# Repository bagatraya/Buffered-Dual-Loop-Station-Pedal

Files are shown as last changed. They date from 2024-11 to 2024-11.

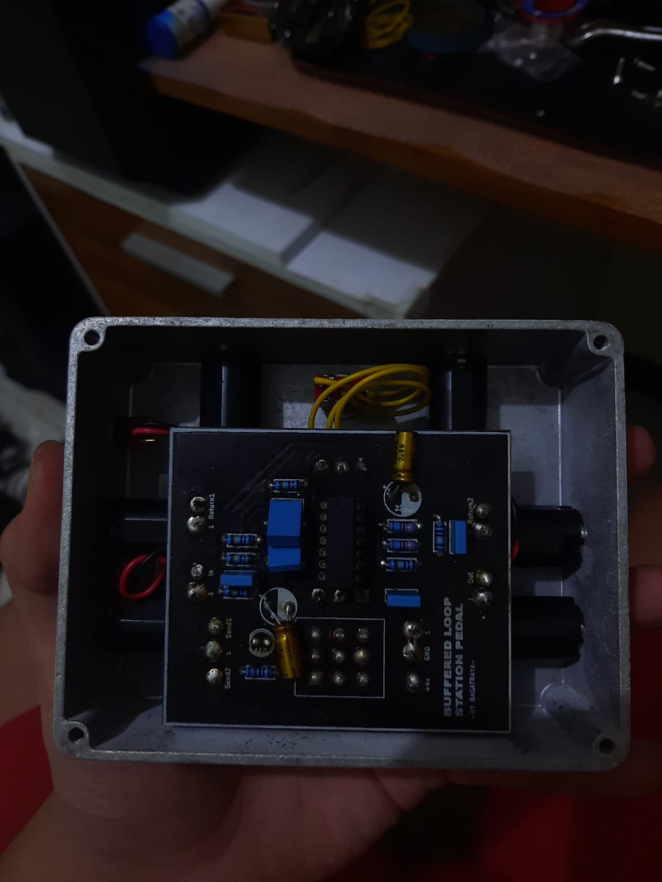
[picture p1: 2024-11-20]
Buffered-Dual-Loop-Station-Pedal/Documentation/5.jpg

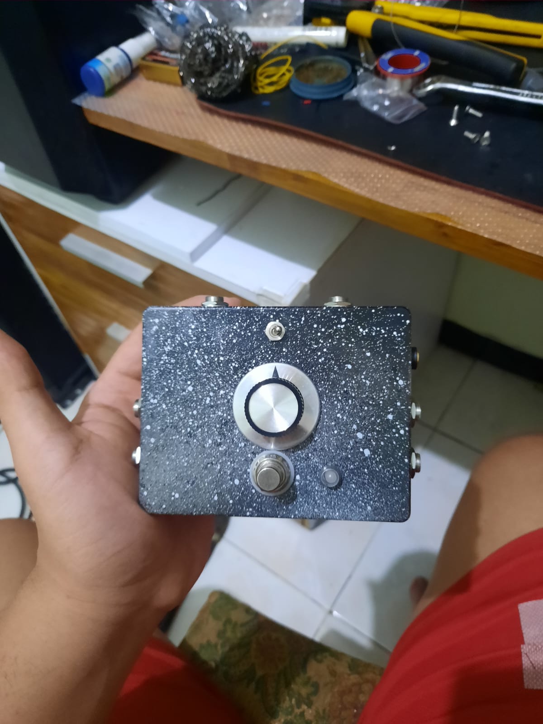
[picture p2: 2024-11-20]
Buffered-Dual-Loop-Station-Pedal/Documentation/6.jpg

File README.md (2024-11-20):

# Buffered-Dual-Loop-Station-Pedal
A project showcasing the design and development of a Buffered Dual Loop Station Effect Pedal, using the TL074 op-amp for low-noise buffering and inverting circuits. This repository includes the schematic, PCB design, simulation files, and a detailed project report.

## Features  
- **Buffered Input and Outputs**: Maintains signal integrity with low-noise TL074 op-amps.  
- **Phase Inversion**: Switchable inverting circuit for phase adjustment on Return 1.  
- **Signal Blending**: Blend potentiometer to control the balance between two return signals.  
- **Live-Tested**: Successfully used in live performance settings.  

## Repository Contents  
- **Hardware**: Schematic, PCB designs, and Bill of Materials (BOM).  
- **Simulations**: Proteus simulation files and results.  
- **Photos and Demos**: Images and video of the build and live testing.

## Simulation
WhatsApp Image 2024-11-06 at 13 19 08_4e2e42fc
WhatsApp Image 2024-11-06 at 13 19 08_1d4611a7

## PCB Circuit
WhatsApp Image 2024-11-20 at 22 16 17_e44410e7

## PCB Design
WhatsApp Image 2024-11-06 at 14 10 15_3a9c0417

## Final Result
WhatsApp Image 2024-11-20 at 22 17 19_efe885c9
WhatsApp Image 2024-11-20 at 22 17 20_f0106ce3

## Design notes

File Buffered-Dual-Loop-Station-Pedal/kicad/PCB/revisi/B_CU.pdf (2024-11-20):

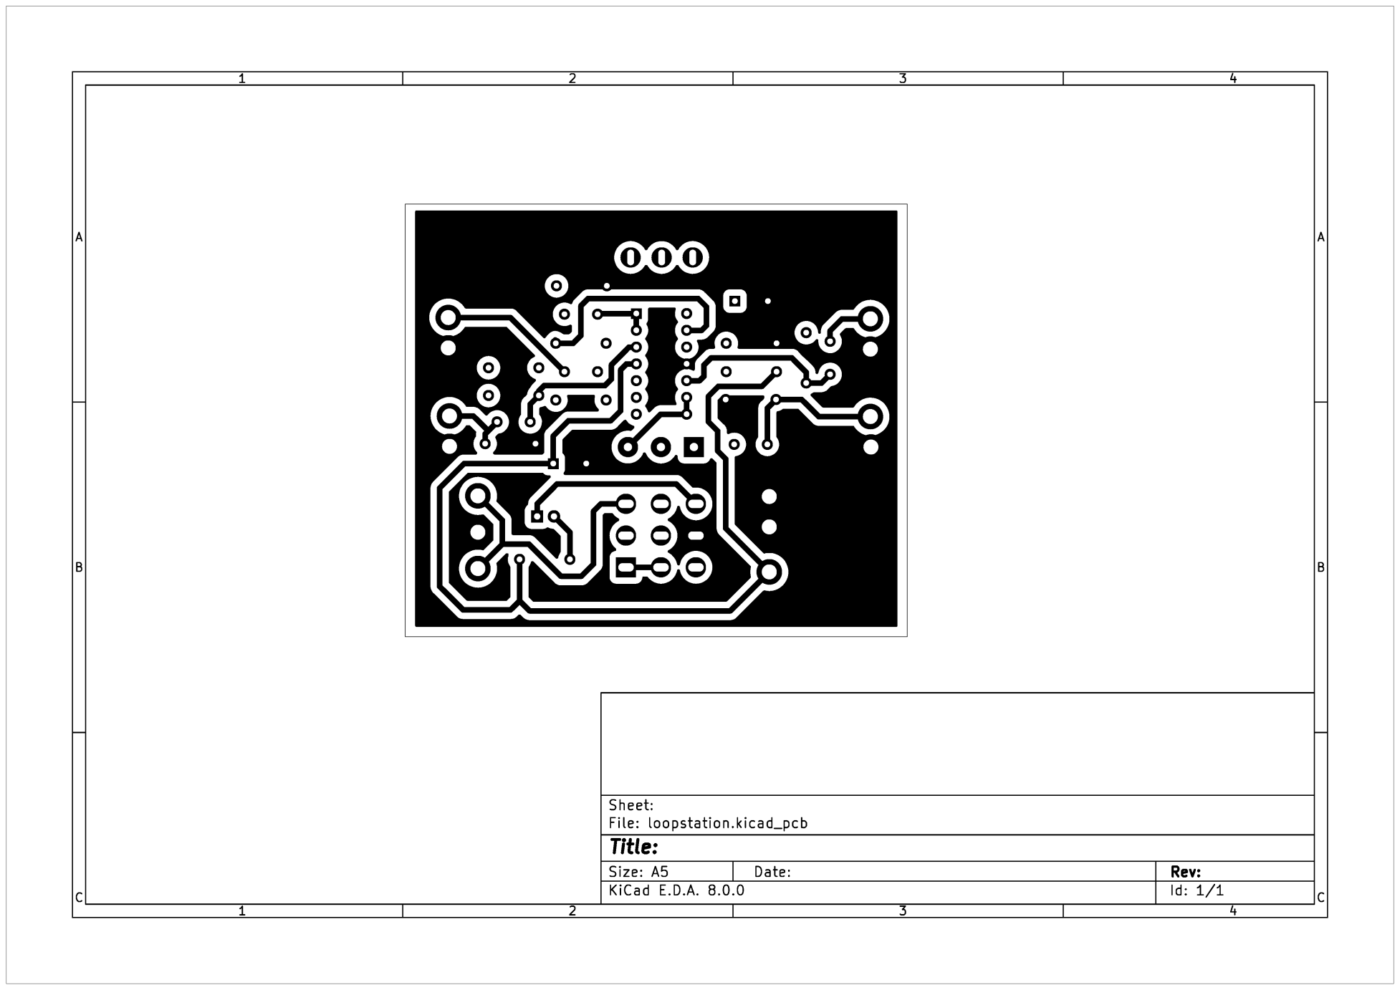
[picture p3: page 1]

2 | 3
A | A

B

Sheet:
File: loopstation.kicad_pcb
Title:
Size: A5 | Date: | Rev:
c~---------,.--------r-----------.,-~Ki_C_ad_E_.D_.A_._B_._o.ro _______ .-----------r----~-ld_:_1_/_1-,,----~c

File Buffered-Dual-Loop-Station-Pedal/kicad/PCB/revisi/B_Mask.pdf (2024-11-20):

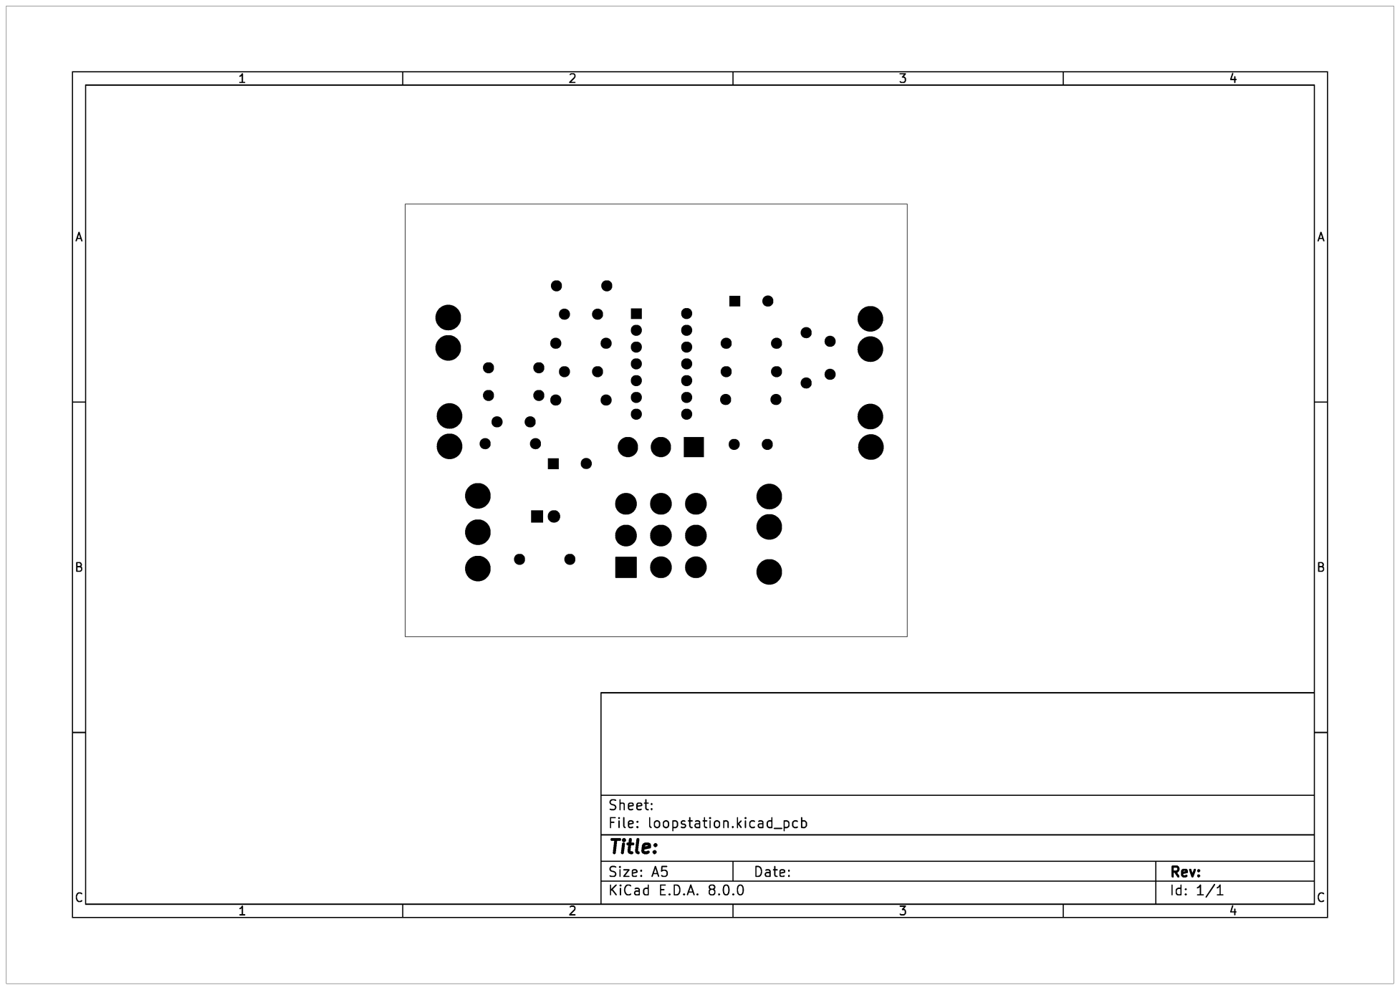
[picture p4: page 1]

1 | 2 | I | 3 | I | 4
A | A
- •
- | ■ | • | • • • ■ | • • • | • • • • • • • • •
- • • • • • • • • • • • •
- •• • • • • • • • • | • • | • • • • | ••• • • ■ | • | • • •• ••• • B | • • •• • • • • • •• • | B

Sheet:
File: loopstation.kicad_pcb
Title:
Size: A5 | I Date: | I Rev:
C | KiCad E.D.A. 8.0.0 | I Id: 1/1 | C 1 | L | ~ | q

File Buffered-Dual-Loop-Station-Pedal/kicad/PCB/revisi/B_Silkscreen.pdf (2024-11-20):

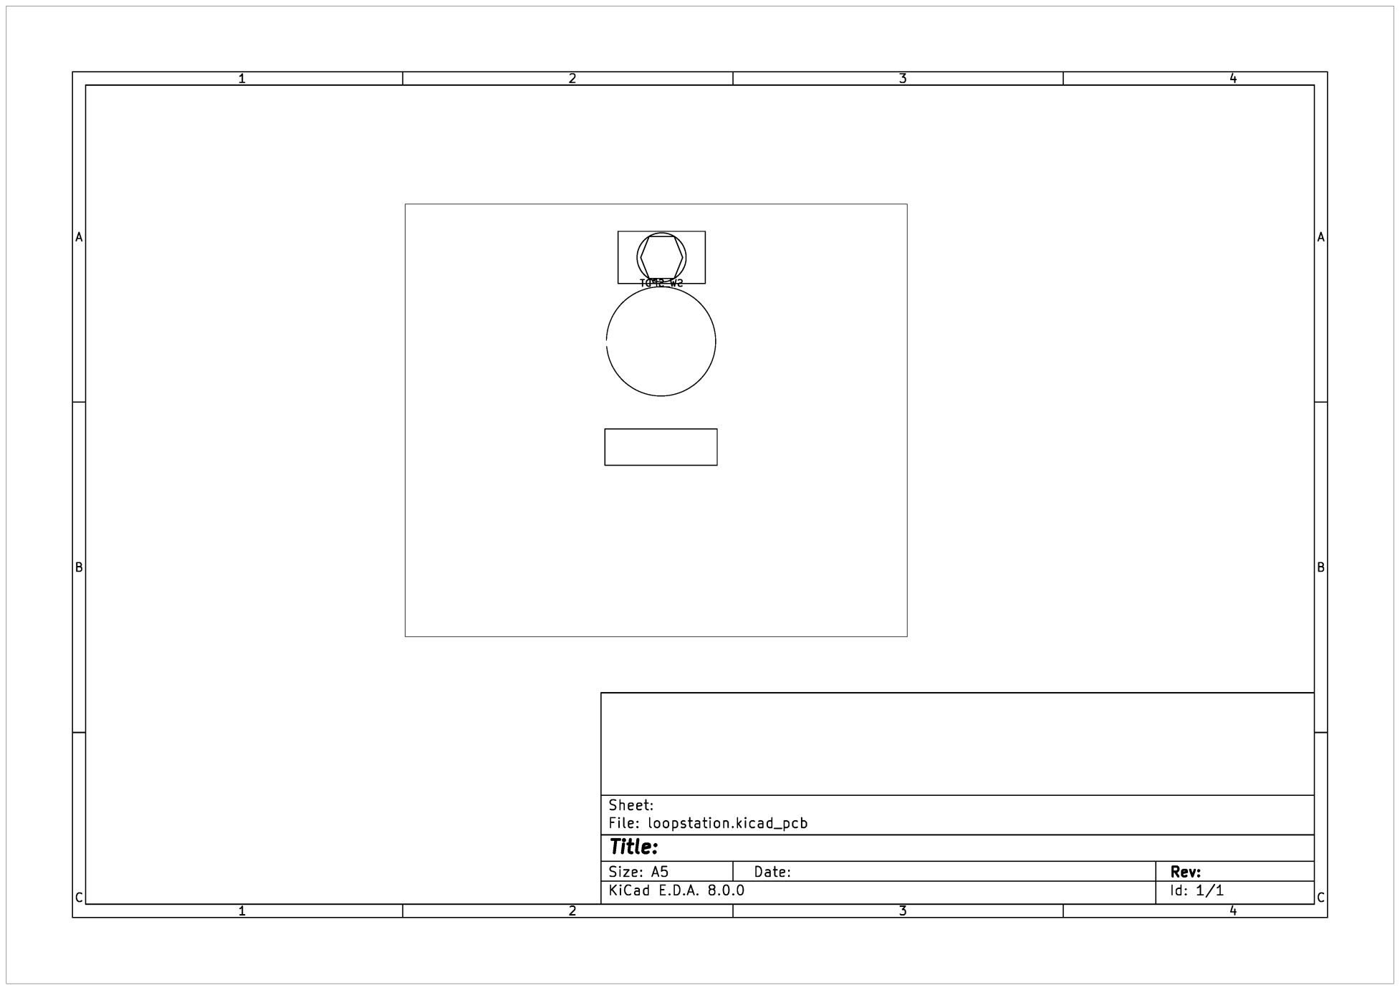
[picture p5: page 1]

1 | 2 | I | 3 | I | 4
A | IOI | A
0
I | I
B | B

Sheet:
File: loopstation.kicad_pcb

## Title:

Size: A5 | I Date: | I Rev:
C | KiCad E.D.A. 8.0.0 | I Id: 1/1 | C 1 | L | ~ | q

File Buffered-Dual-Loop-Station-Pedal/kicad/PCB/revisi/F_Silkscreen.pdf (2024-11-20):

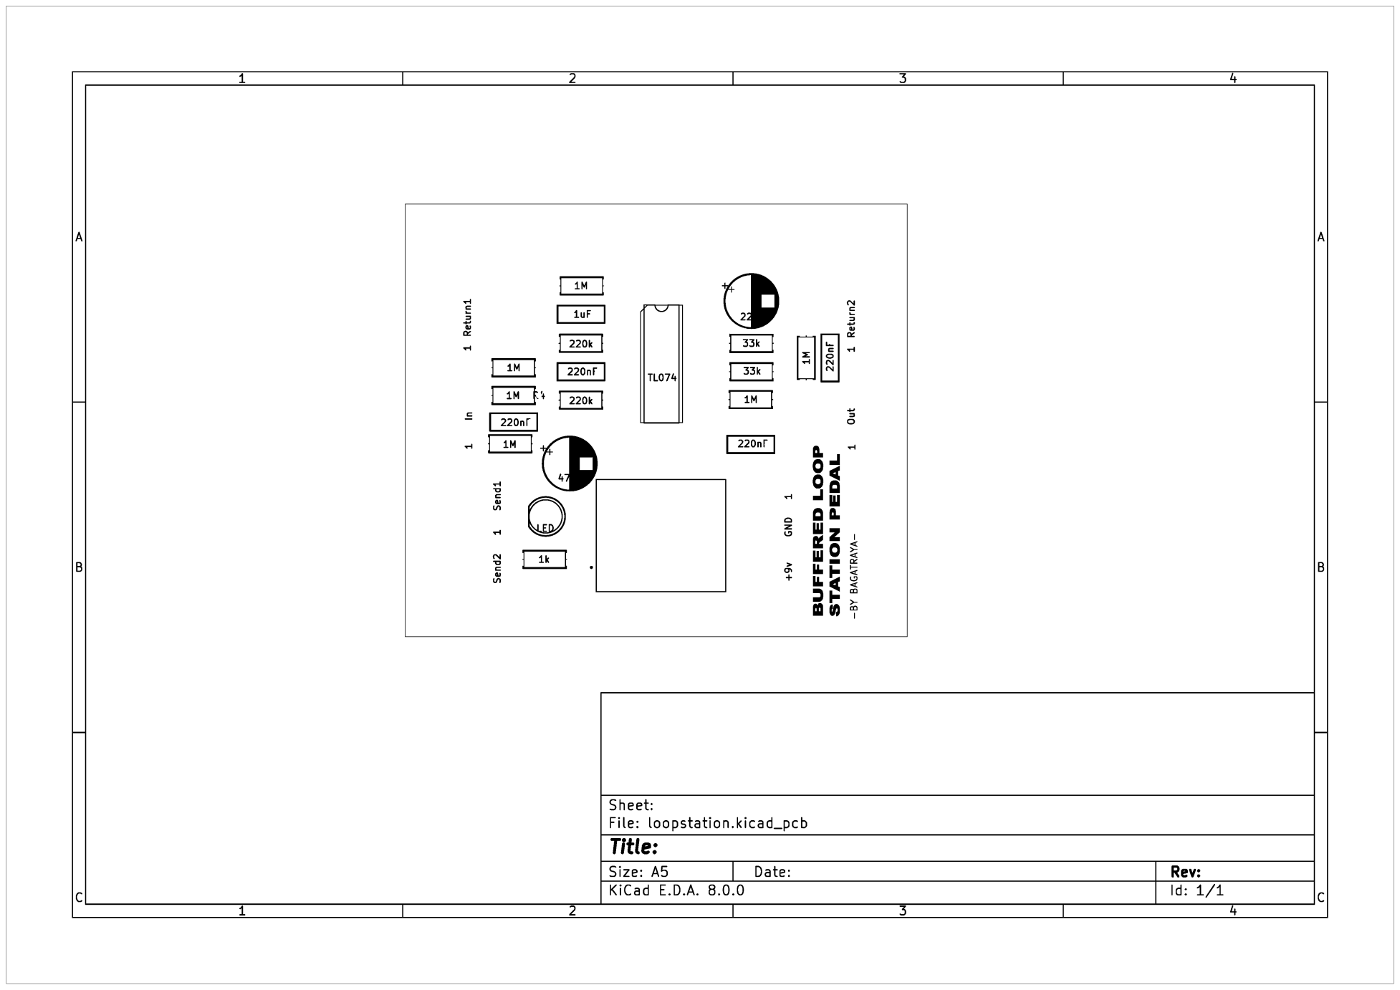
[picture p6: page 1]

2 | I | 3 | I | 4
A | A

~

B

Sheet:
File: loopstation.kicad_pcb
Title:
Size: A5 | I Date: | I Rev:
c~------.--------r-----------.,-~Ki_C_ad_E_.D_.A_._B_._o.ro _______ .-----------r----~l_ld_:_1_/_1-,,----~c 1 | L | j | 4

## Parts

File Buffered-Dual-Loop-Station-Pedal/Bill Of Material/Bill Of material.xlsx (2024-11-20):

NO | nama barang | Harga | jumlah | sub total
1 | PCB | Rp 52000.00 | 1 | Rp 52000.00
2 | Rumah LED 5mm | Rp 2000.00 | 1 | Rp 2000.00
3 | LED 5mm | Rp 700.00 | 2 | Rp 1400.00
4 | resistor 33k | Rp 650.00 | 2 | Rp 1300.00
5 | resistor 220k | Rp 650.00 | 2 | Rp 1300.00
6 | resistor 1k | Rp 650.00 | 1 | Rp 650.00
7 | resistor 1M | Rp 800.00 | 6 | Rp 4800.00
8 | SPDT 3pin ON-ON | Rp 9000.00 | 1 | Rp 9000.00
9 | Socket IC 14 pin | Rp 2500.00 | 1 | Rp 2500.00
10 | Footswitch 3PDT | Rp 26000.00 | 1 | Rp 26000.00
11 | Socket DC 2.1x5.5mm | Rp 3600.00 | 1 | Rp 3600.00
12 | knob potensio | Rp 12500.00 | 1 | Rp 12500.00
13 | potentiometer b25k | Rp 7500.00 | 1 | Rp 7500.00
14 | case alu 1590BB2 | Rp 102000.00 | 1 | Rp 102000.00
15 | cap elco 22uF | Rp 4750.00 | 1 | Rp 4750.00
16 | Epcos 220nF | Rp 2800.00 | 4 | Rp 11200.00
17 | cap elco 47uF | Rp 3500.00 | 1 | Rp 3500.00
18 | Epcos 1uF | Rp 4500.00 | 1 | Rp 4500.00
19 | Socket jack 6.35mm | Rp 6500.00 | 6 | Rp 39000.00
20 | IC TL074 | Rp 6500.00 | 1 | Rp 6500.00
 |  |  | TOTAL | Rp 296000.00

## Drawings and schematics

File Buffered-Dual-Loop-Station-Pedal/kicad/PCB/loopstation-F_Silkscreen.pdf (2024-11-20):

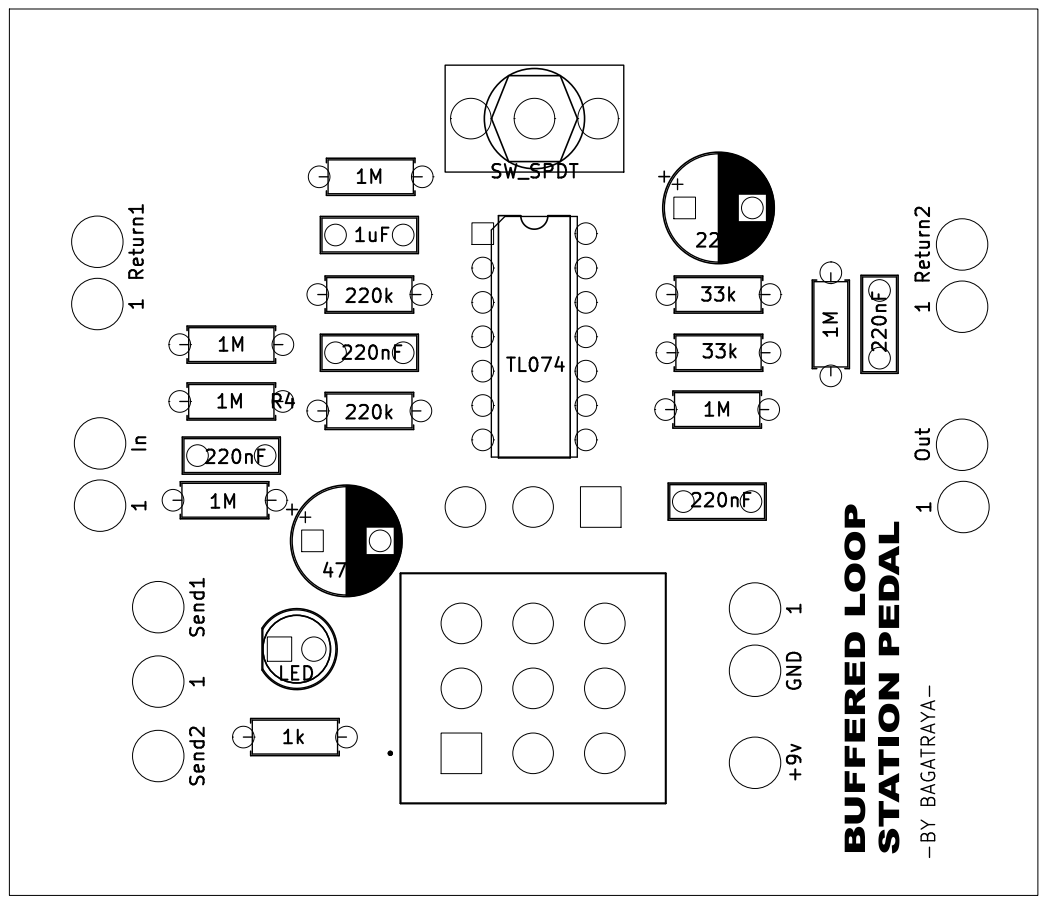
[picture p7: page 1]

BUFFERED LOOP STATION PEDAL -BY BAGATRAYA- Send2 Send1 GND

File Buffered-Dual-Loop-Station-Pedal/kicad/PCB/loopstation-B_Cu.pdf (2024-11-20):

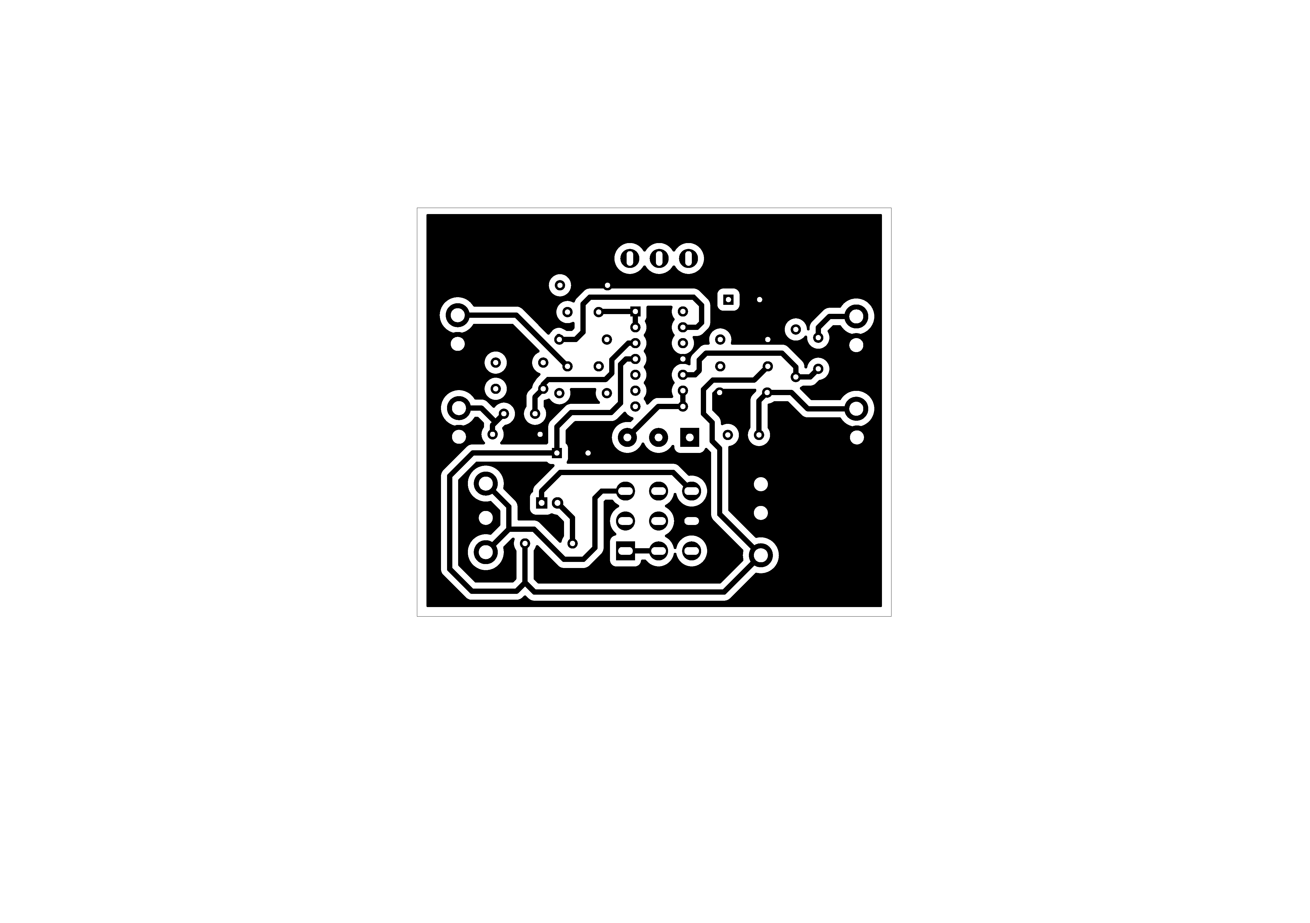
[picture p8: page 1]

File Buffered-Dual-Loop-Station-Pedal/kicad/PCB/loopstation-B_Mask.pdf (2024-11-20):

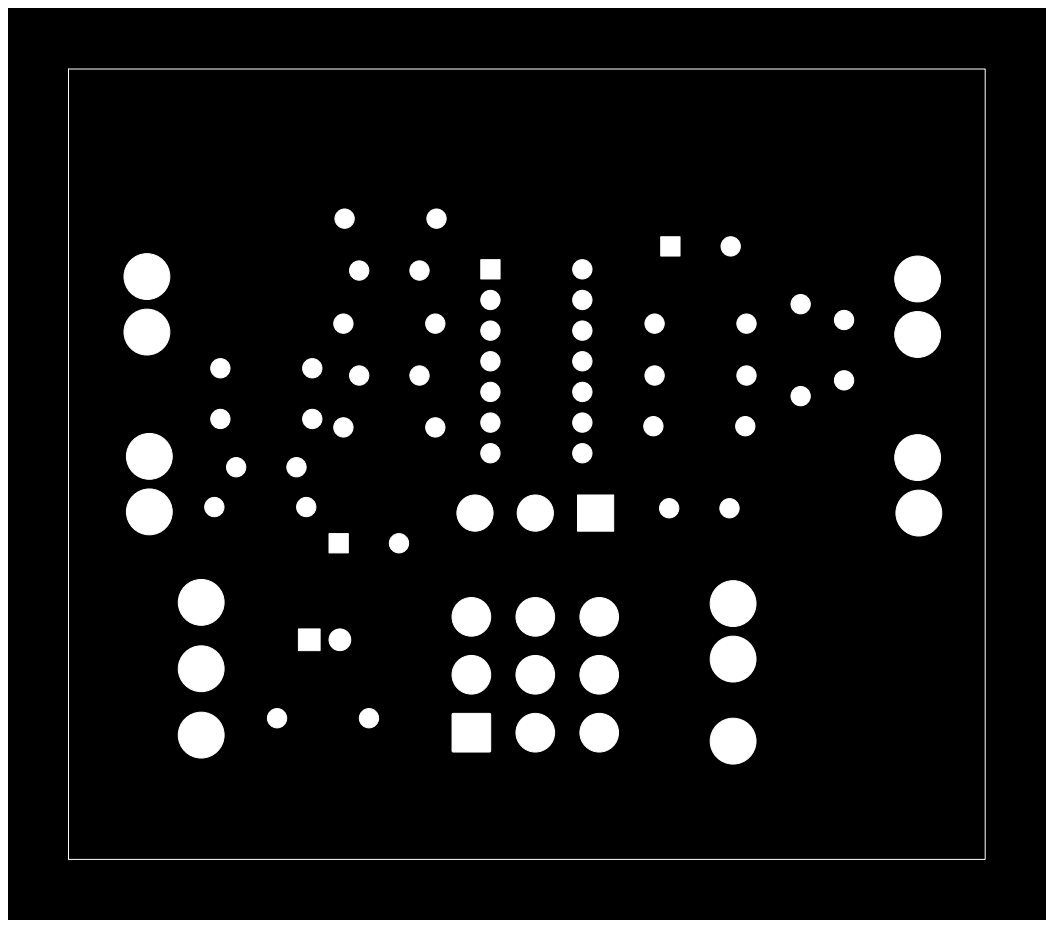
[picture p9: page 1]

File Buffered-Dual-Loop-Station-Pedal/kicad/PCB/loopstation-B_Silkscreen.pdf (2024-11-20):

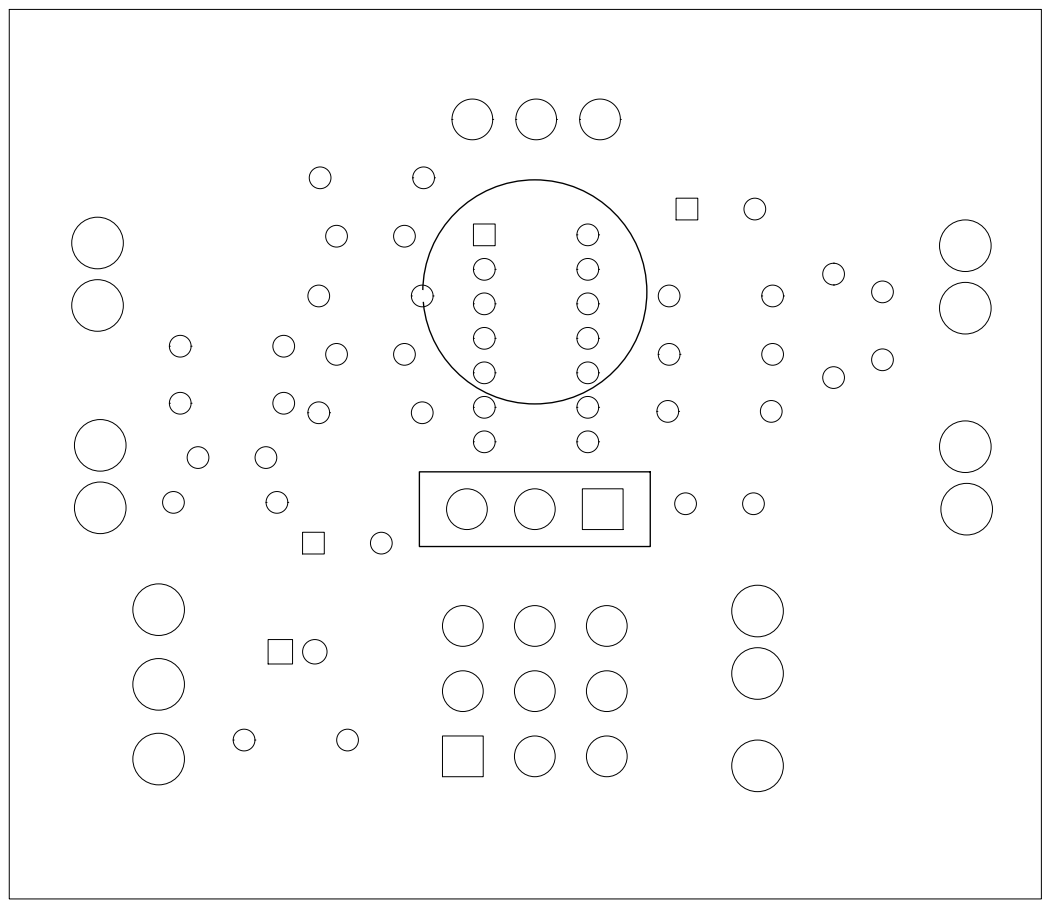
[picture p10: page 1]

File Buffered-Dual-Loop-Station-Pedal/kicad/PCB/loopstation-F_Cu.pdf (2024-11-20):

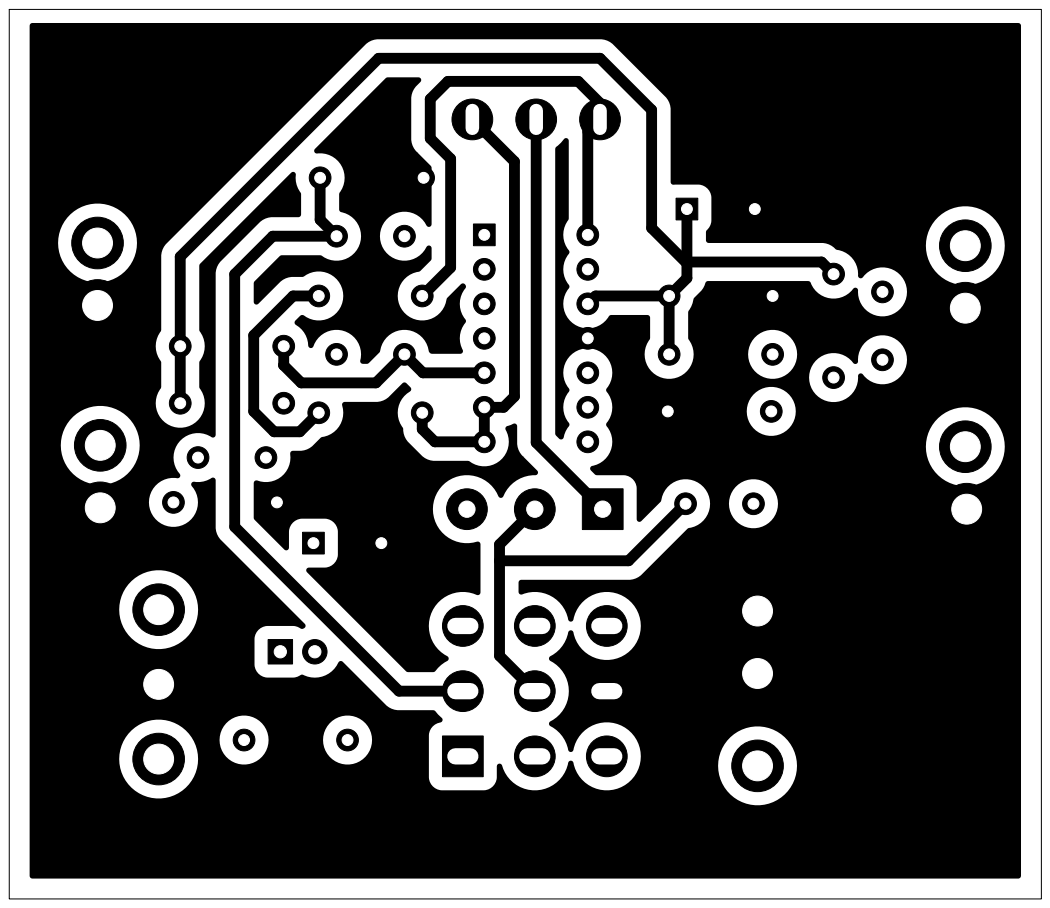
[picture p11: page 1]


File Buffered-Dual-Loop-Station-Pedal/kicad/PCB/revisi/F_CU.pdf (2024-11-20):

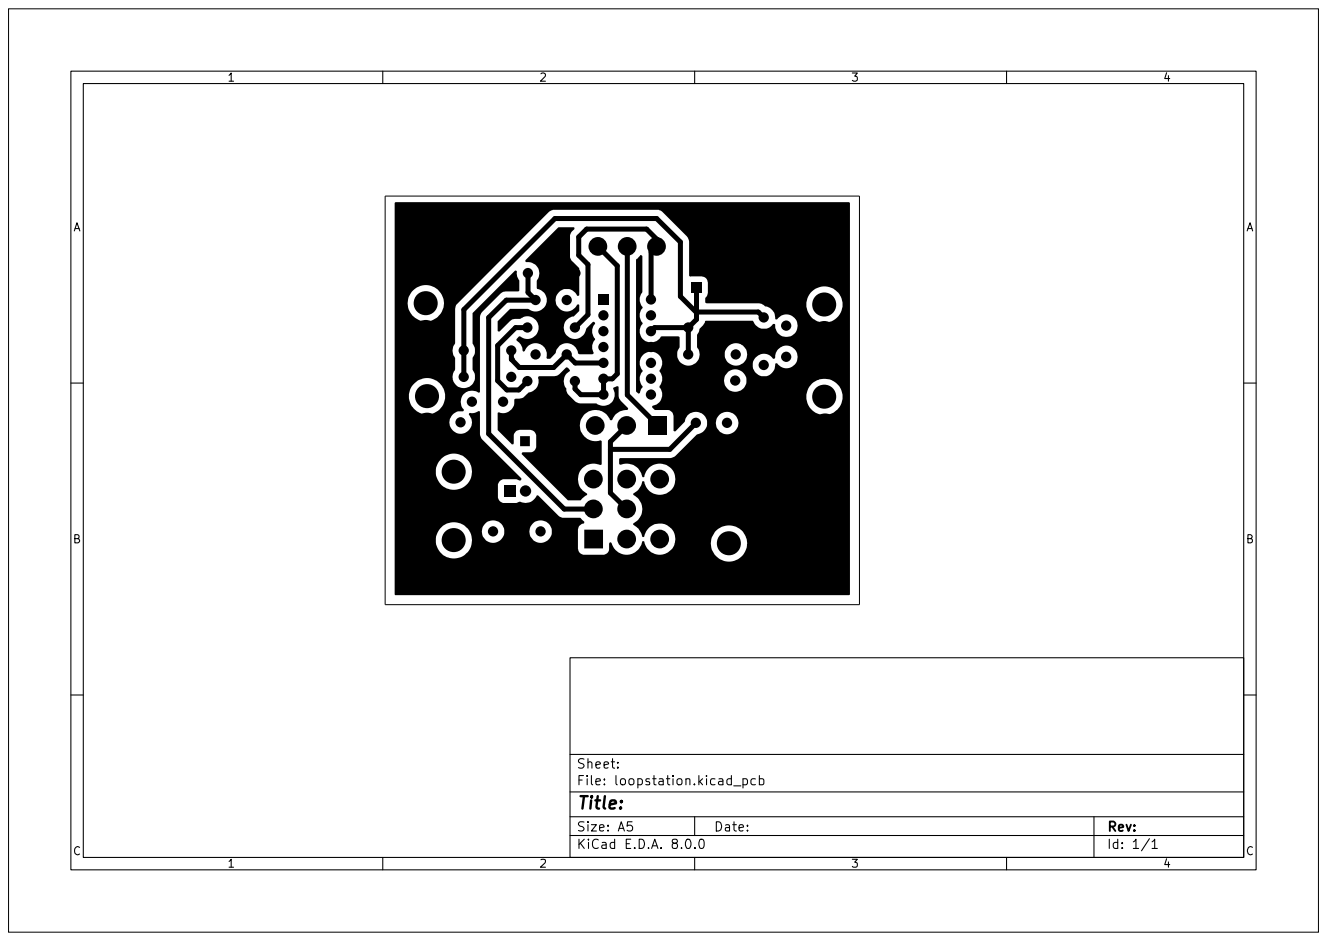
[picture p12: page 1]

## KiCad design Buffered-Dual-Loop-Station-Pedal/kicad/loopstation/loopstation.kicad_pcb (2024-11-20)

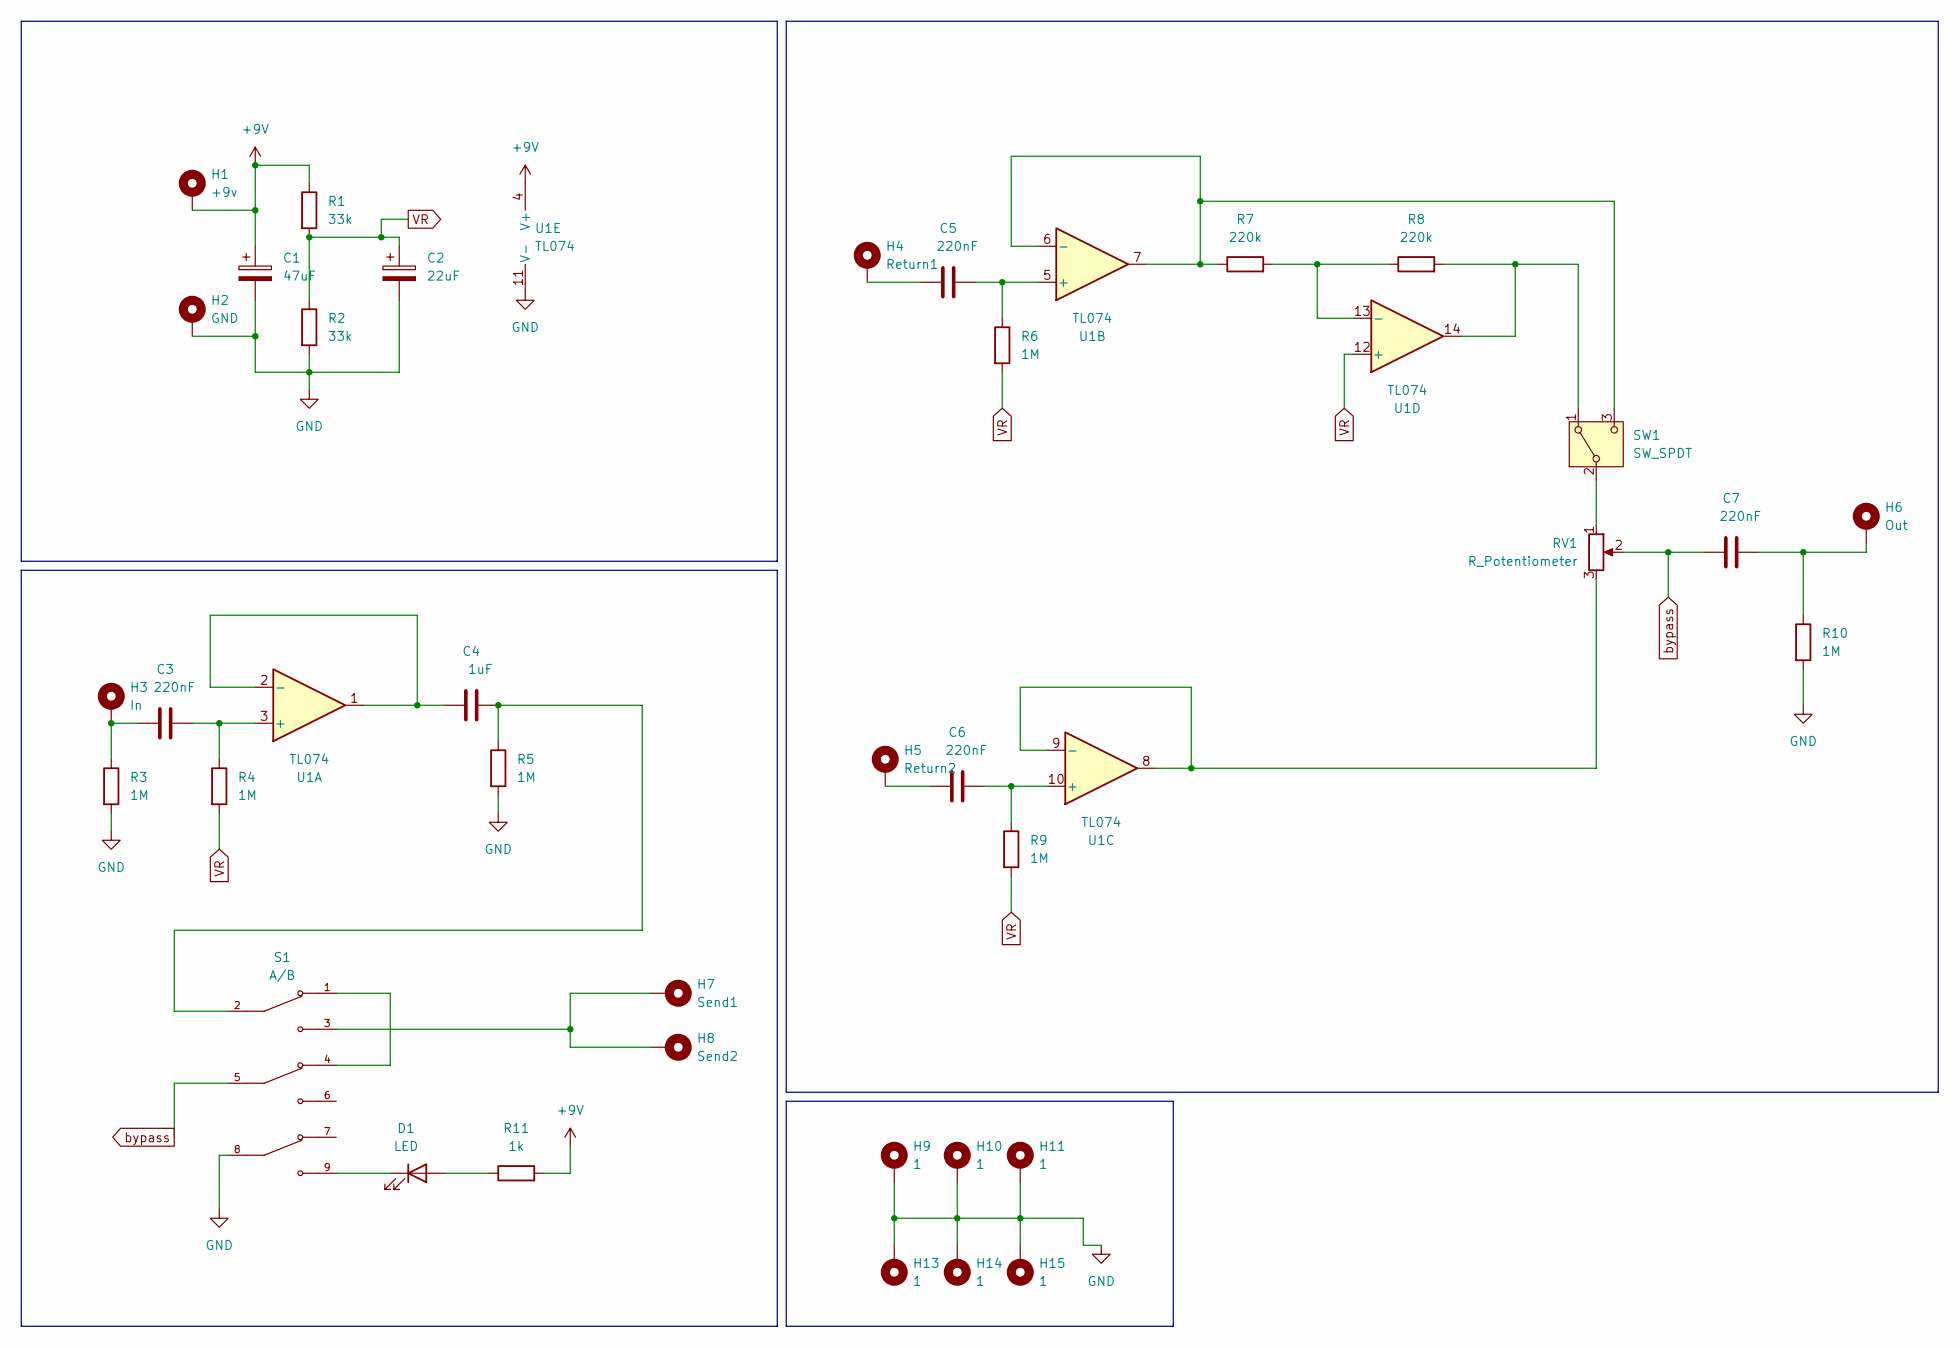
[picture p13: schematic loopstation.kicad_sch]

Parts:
C1: 47uF; CP_Radial_D8.0mm_P5.00mm
C2: 22uF; CP_Radial_D8.0mm_P5.00mm
C3, C5, C6, C7: 220nF; C_Rect_L7.0mm_W2.5mm_P5.00mm
C4: 1uF; C_Rect_L7.0mm_W2.5mm_P5.00mm
D1: LED; LED_D5.0mm
H1: +9v; MountingHole_2.2mm_M2_DIN965_Pad
H2: GND; MountingHole_2.2mm_M2_DIN965_Pad
H3: In; MountingHole_2.2mm_M2_DIN965_Pad
H4: Return1; MountingHole_2.2mm_M2_DIN965_Pad
H5: Return2; MountingHole_2.2mm_M2_DIN965_Pad
H6: Out; MountingHole_2.2mm_M2_DIN965_Pad
H7: Send1; MountingHole_2.2mm_M2_DIN965_Pad
H8: Send2; MountingHole_2.2mm_M2_DIN965_Pad
H9, H10, H11, H13, H14, H15: 1; MountingHole_2.2mm_M2_DIN965_Pad
R1, R2: 33k; R_Axial_DIN0207_L6.3mm_D2.5mm_P7.62mm_Horizontal
R3, R4, R5, R6, R9, R10: 1M; R_Axial_DIN0207_L6.3mm_D2.5mm_P7.62mm_Horizontal
R7, R8: 220k; R_Axial_DIN0207_L6.3mm_D2.5mm_P7.62mm_Horizontal
R11: 1k; R_Axial_DIN0207_L6.3mm_D2.5mm_P7.62mm_Horizontal
RV1: R_Potentiometer; Potentiometer_Alps_RK163_Single_verticalback
S1: A/B; SW_FS57003PLT2B2M2QE; PARTREV 4.2.2018
SW1: SW_SPDT; SPDT
U1: TL074; DIP-14_W7.62mm

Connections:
+9V: C1.1, H1.1, R1.1, R11.2, U1.4 (V+)
GND: C1.2, C2.2, H2.1, H9.1, H10.1, H11.1, H13.1, H14.1, H15.1, R2.2, R3.2, R5.2, R10.2, S1.8, U1.11 (V-)
unnamed: C3.1, H3.1, R3.1
unnamed: C4.2, R5.1, S1.2
unnamed: C5.1, H4.1
unnamed: C6.1, H5.1
unnamed: C7.2, H6.1, R10.1
unnamed: D1.2 (A), R11.1
unnamed: D1.1 (K), S1.9
unnamed: H7.1, H8.1, S1.3
unnamed: S1.1, S1.4
unnamed: R8.2, SW1.1 (A), U1.14
unnamed: RV1.1, SW1.2 (B)
unnamed: R7.1, SW1.3 (C), U1.6 (-), U1.7
unnamed: C3.2, R4.1, U1.3 (+)
unnamed: C4.1, U1.1, U1.2 (-)
unnamed: C5.2, R6.1, U1.5 (+)
unnamed: C6.2, R9.1, U1.10 (+)
unnamed: RV1.3, U1.8, U1.9 (-)
unnamed: R7.2, R8.1, U1.13 (-)
VR: C2.1, R1.2, R2.1, R4.2, R6.2, R9.2, U1.12 (+)
bypass: C7.1, RV1.2, S1.5

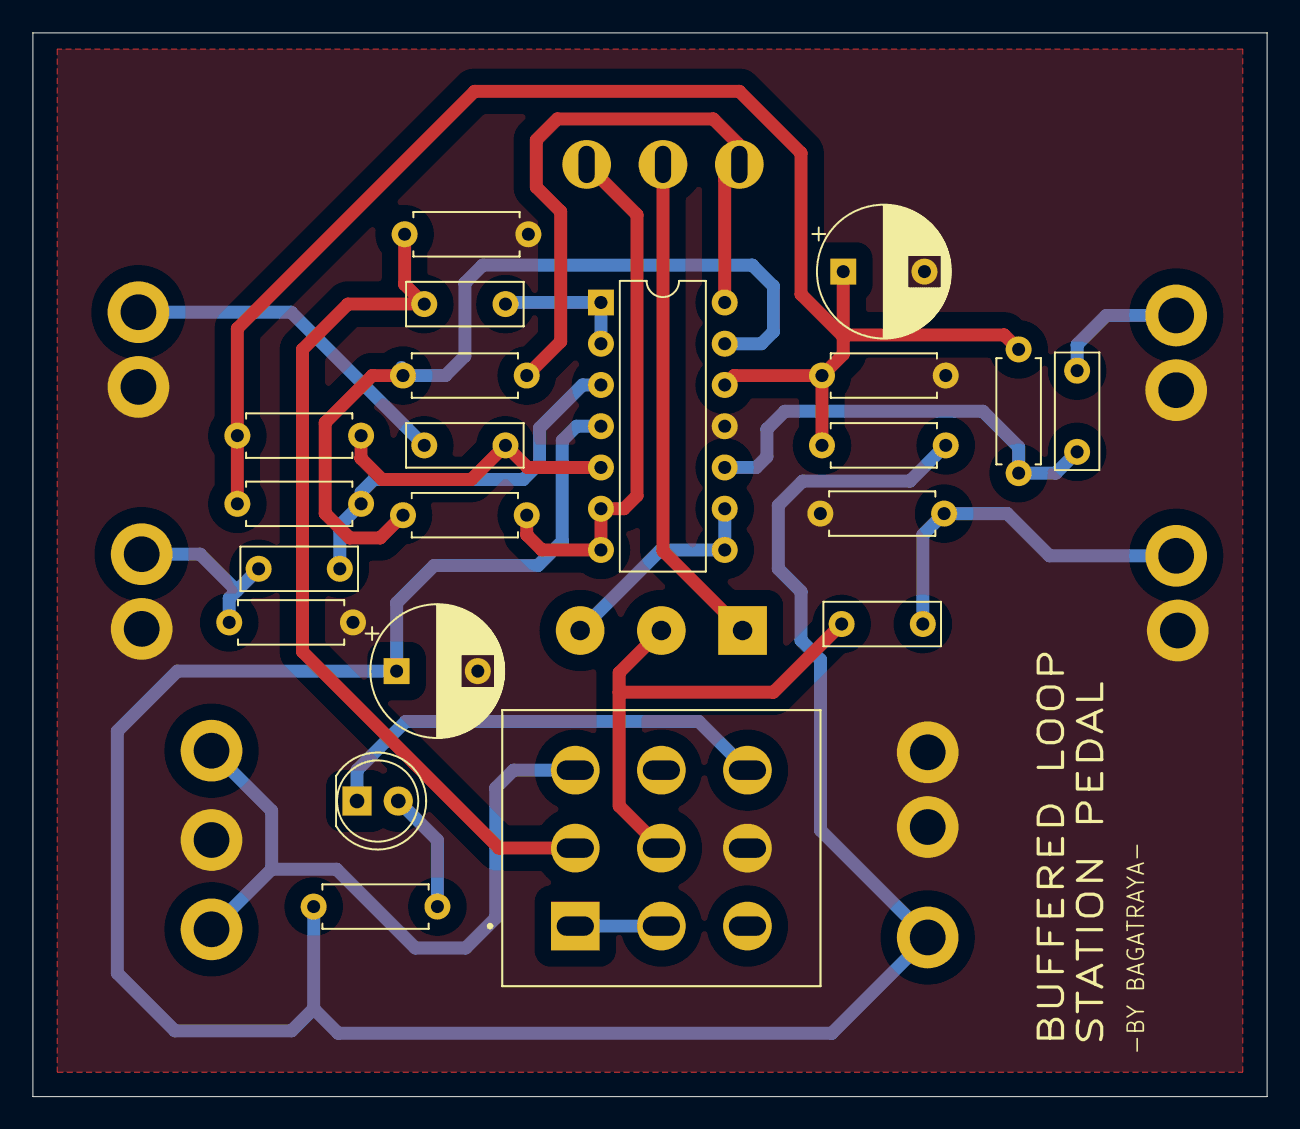
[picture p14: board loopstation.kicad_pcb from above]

Board: 2 copper layers, 76.0 x 65.5 mm, 37 parts (1 on the bottom side), 22 nets.
